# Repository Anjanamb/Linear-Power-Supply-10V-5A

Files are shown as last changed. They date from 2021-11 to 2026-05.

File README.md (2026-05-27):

# Linear Power Supply — 10 V, 5 A

> Linear bench power supply targeting **10 V / 5 A**. Concept, simulations, PCB layout, enclosure model, slides, and project report.






> ⚠ **Mains voltages involved.** Only qualified individuals should build or test this. Follow proper electrical safety practices.

---

## Topology

- Step-down transformer 230 V AC → low-voltage AC
- Linear regulation to 10 V DC at up to 5 A
- Short-circuit protection (fast electronic fuse behaviour)
- Over-voltage protection (crowbar / thyristor)
- Negative-voltage protection at output
- Foldback current limiting
- Thermal management via fan-regulation circuit
- PCB layout (Altium) + 3D enclosure (SolidWorks) + Multisim simulations

## Repository structure

```
Linear-Power-Supply-10V-5A/
├─ Circuit/
│  ├─ Fan-Regulation_Circuit.png
│  ├─ Fan-Regulation_Simulation.ms14
│  ├─ Main_Regulation_Circuit.png
│  ├─ Over-Voltage_Protection.png
│  ├─ Short-Circuit_Protection.png
│  └─ Simulation Circuit.ms14
├─ Datasheets/Over Voltage/             # Component datasheets
├─ PCB/                                 # Altium PCBs
├─ Enclosure_Design.SLDASM              # SolidWorks assembly
├─ Presentation.pptx
├─ Project Report.pdf
└─ components & datasheets.ptpm
```

## License

[MIT](LICENSE) — see [anjanamb.github.io](https://anjanamb.github.io/) for more projects.

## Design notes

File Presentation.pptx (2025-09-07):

## LINEAR POWER SUPPLY

Group No. - 05

## Basic Idea

Stepped down source
(230 V rms-15 V rms)

Short circuit protection

Regulator circuit

Current divider circuit

Feedback circuit

Foldback Current circuit

Output
(Voltage 10V
Current 5A)

Over voltage protection

## SCHEMATIC DIAGRAMS

## MAIN REGULATION CIRCUIT

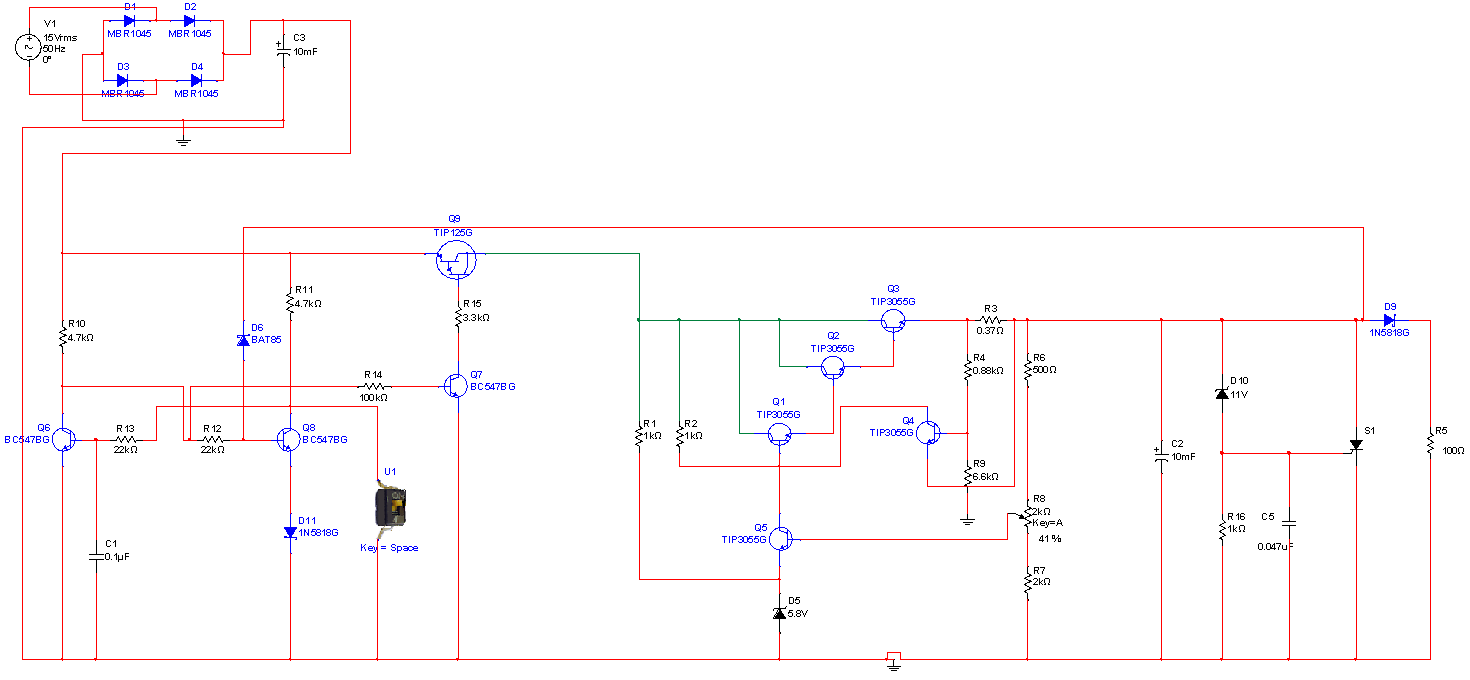
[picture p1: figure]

## FAN REGULATION CIRCUIT

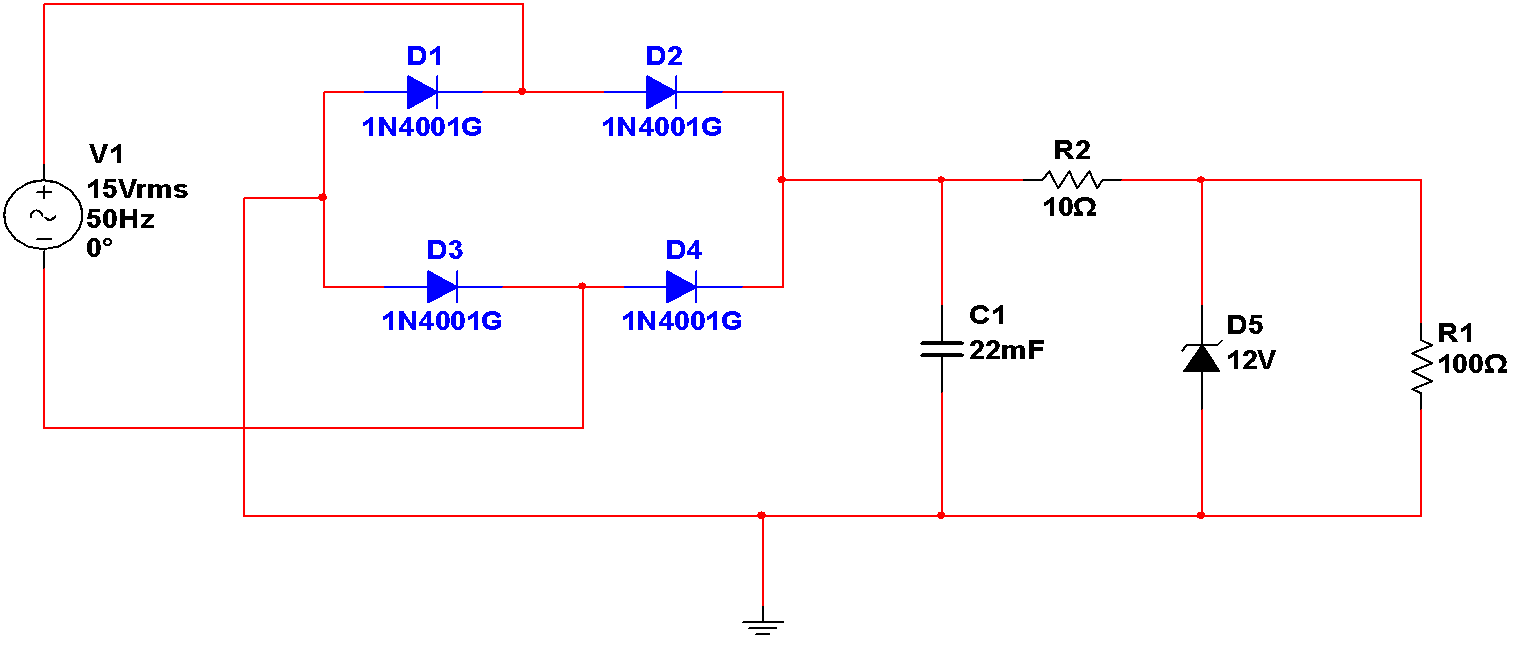
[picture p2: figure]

## CIRCUIT EXPLANATION

## Main regulation parts

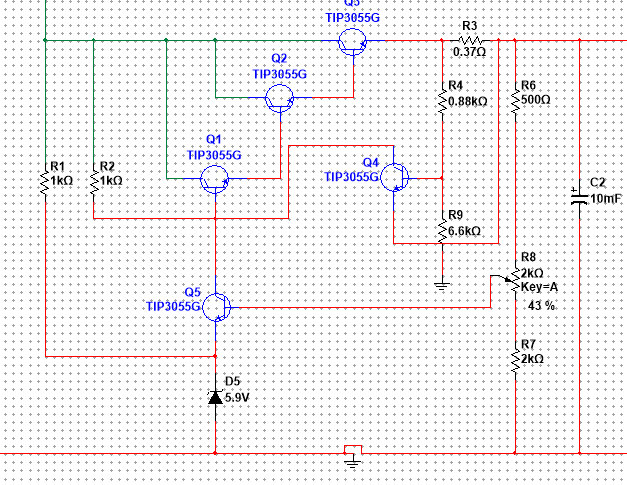
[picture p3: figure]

- Regulator
- Current divider
- Feedback
- Foldback Current

VBE(Q4)= K IL R5 + (K – 1) Vout
K= (R9 / R4+ R9)

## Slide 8

Feedback circuit Calculations
VBE(Q5) + V(D5) = R7 / (R7 + R6) * Vout
Vout = (1 + R6/R7) (VBE(Q5) + V(D5) ) 01
Vout =10v V(D5) =5.9v VBE(Q5) =0.7v
From 01, R7 ≈2 R6
Foldback current limiting circuit calculations
VB(Q4) = Vout + VBE(Q4) 01 K = R9 / R9 + R4
VB(Q4) = (Vout + R3 IL )K 02
So, Vout + VBE(Q4) = (Vout + R3 IL )K
Vout =10v ILmax=5.5A VBE(Q4) =0.7v & choose R3 =0.37Ohm
By substituting values, K = 0.889
So, R9≈8 R4.

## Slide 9

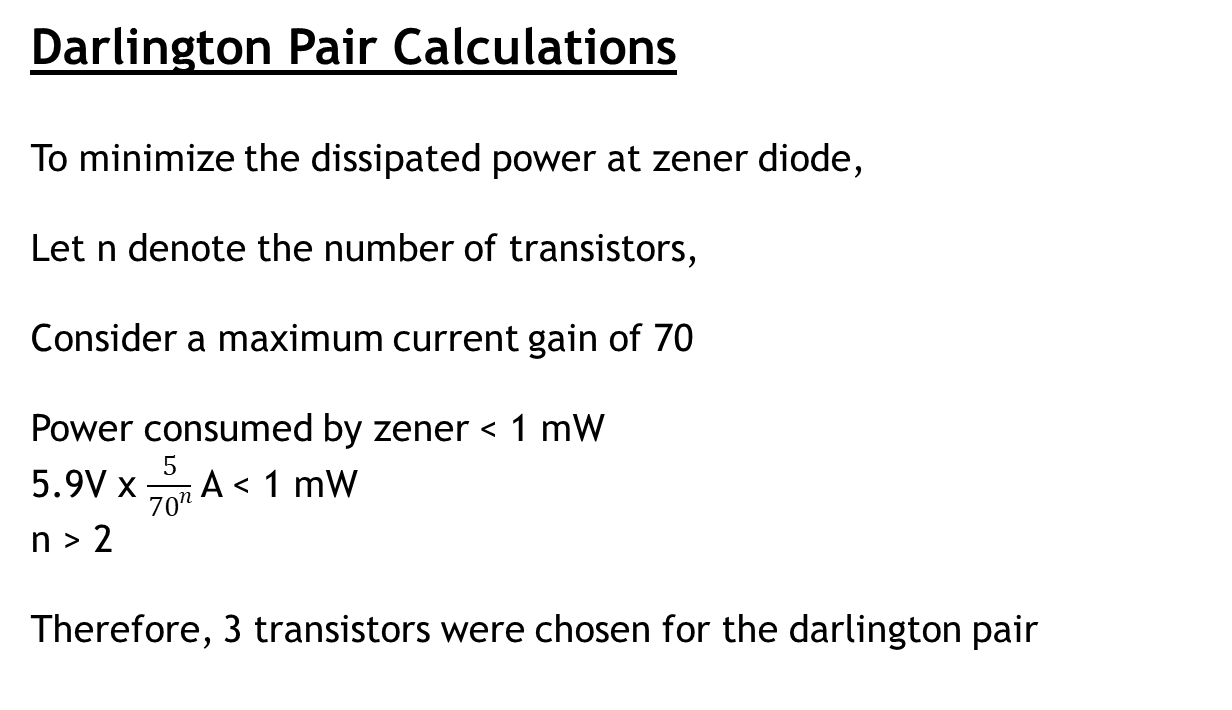
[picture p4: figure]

## Circuit Protections

- Short Circuit Protection

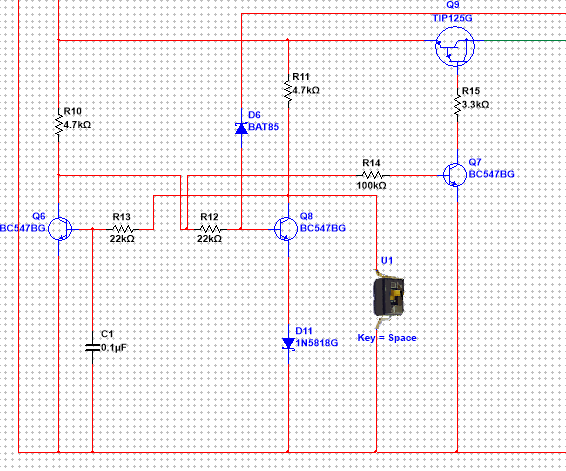
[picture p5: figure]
Screen Clipping

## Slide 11

- Over Voltage Protection
- Over Load Protection

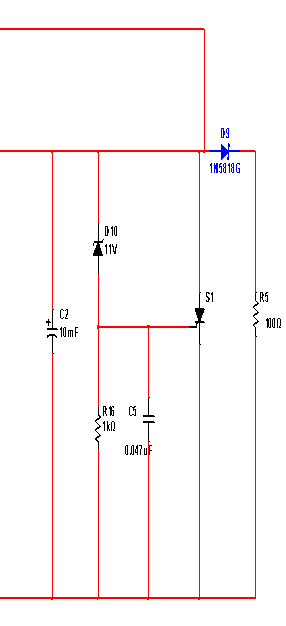
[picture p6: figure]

## Over Voltage Protection circuit calculation

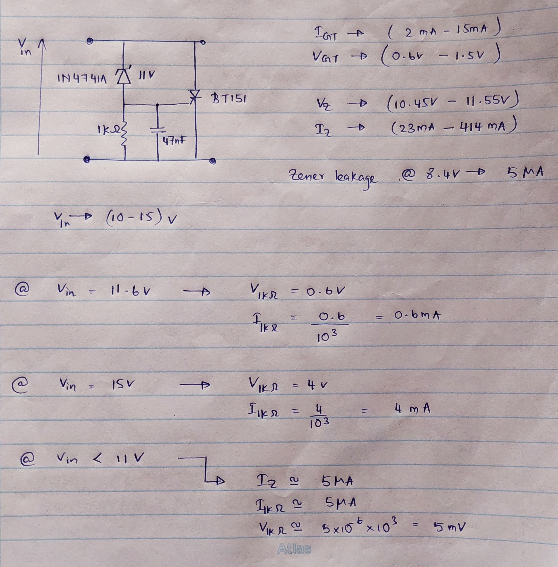
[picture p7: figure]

## SIMULATION RESULTS

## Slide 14

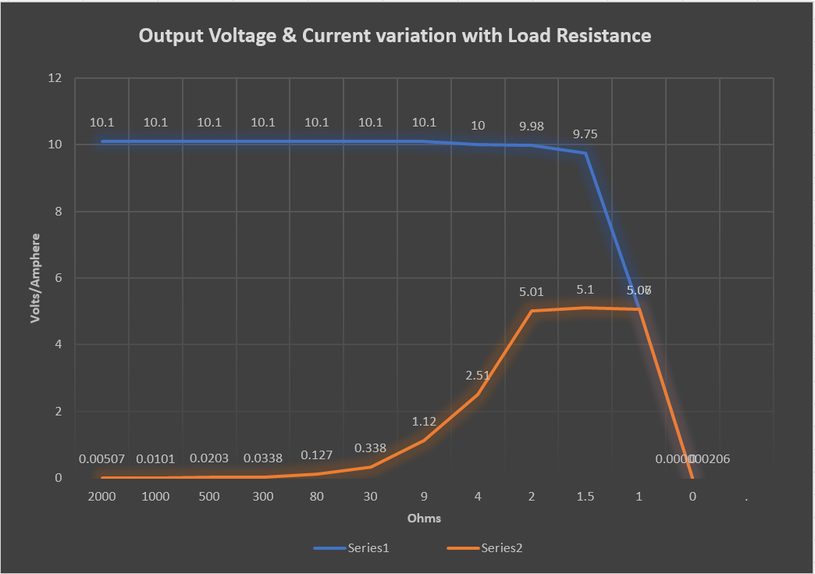
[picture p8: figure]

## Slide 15

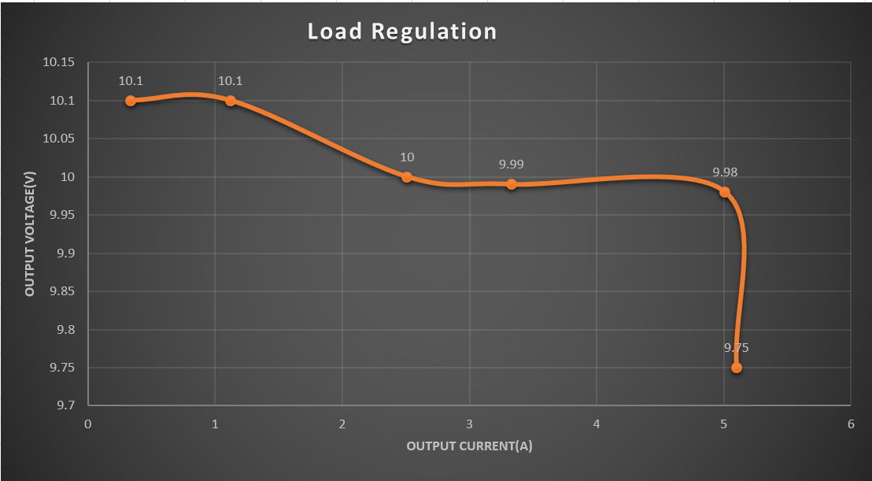
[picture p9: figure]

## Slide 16

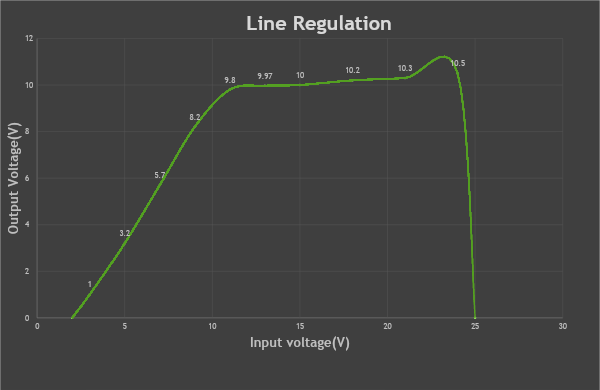
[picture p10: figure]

## Accuracy

- Accuracy = output voltage at maximum current/required output voltage
= 9.79/10 * 100%
= 97.9%

## Breadboard Implementation

Load Resistance (ohms) | Output voltage (V)
2000 | 10.2
1000 | 10.1
500 | 10.1
100 | 9.7
50 | 9
30 | 8.1
10 | 7.3
5 | 6.9
2 | 6.5

- When output current increase for small load resistance, the voltage loses from the bred board and jumper wires increases. So that output voltage dropped from a huge amount.

## COMPLETION PLAN

## ENCLOSURE DESIGN

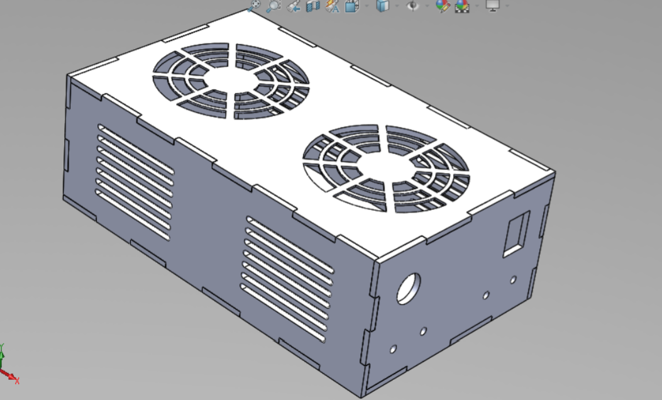
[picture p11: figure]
Screen Clipping

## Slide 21

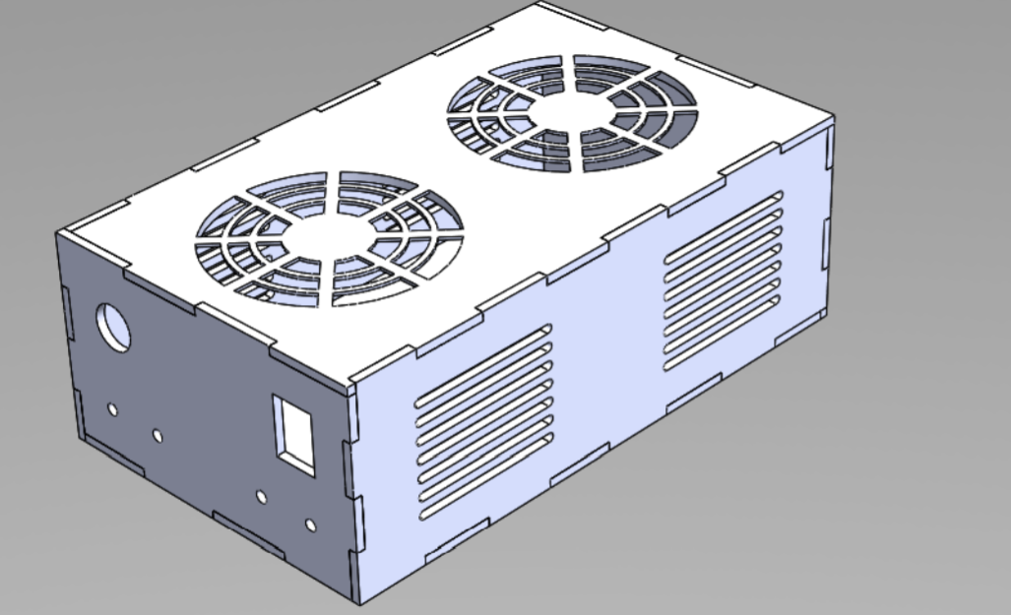
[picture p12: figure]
Screen Clipping

## PCB DESIGN

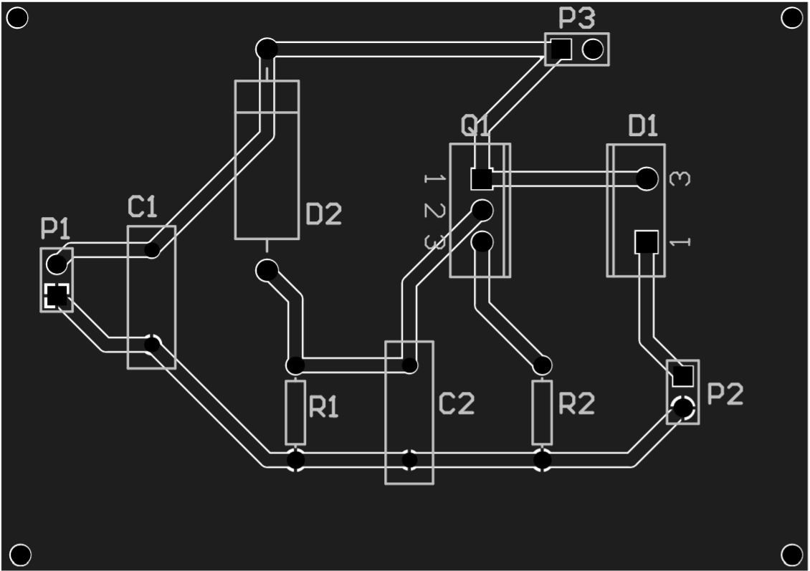
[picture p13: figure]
Screen Clipping

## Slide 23

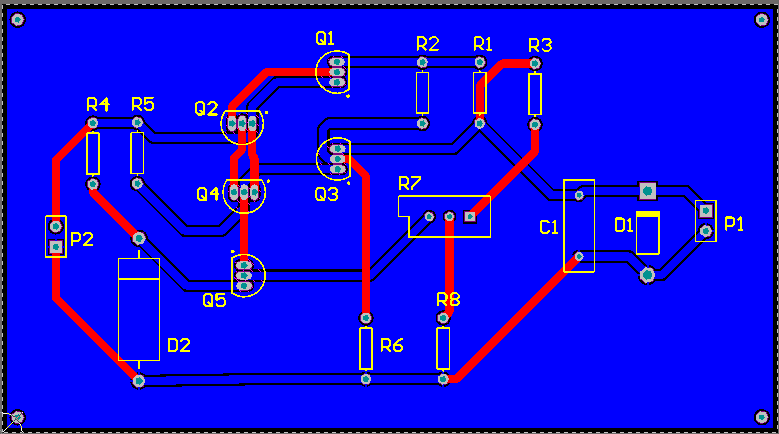
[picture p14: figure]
Screen Clipping

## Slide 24

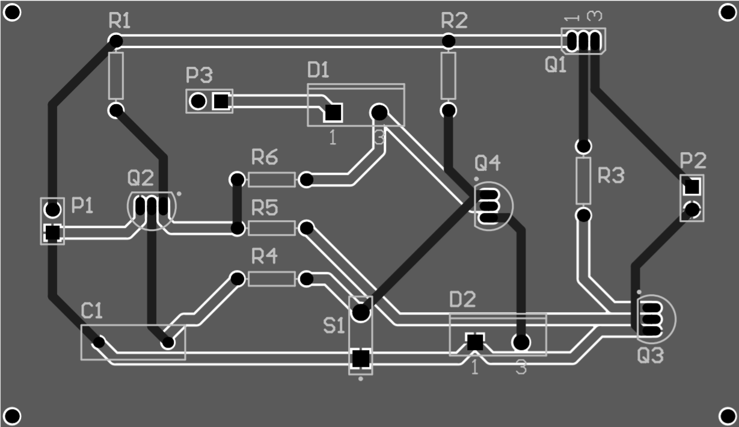
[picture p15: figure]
Screen Clipping

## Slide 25

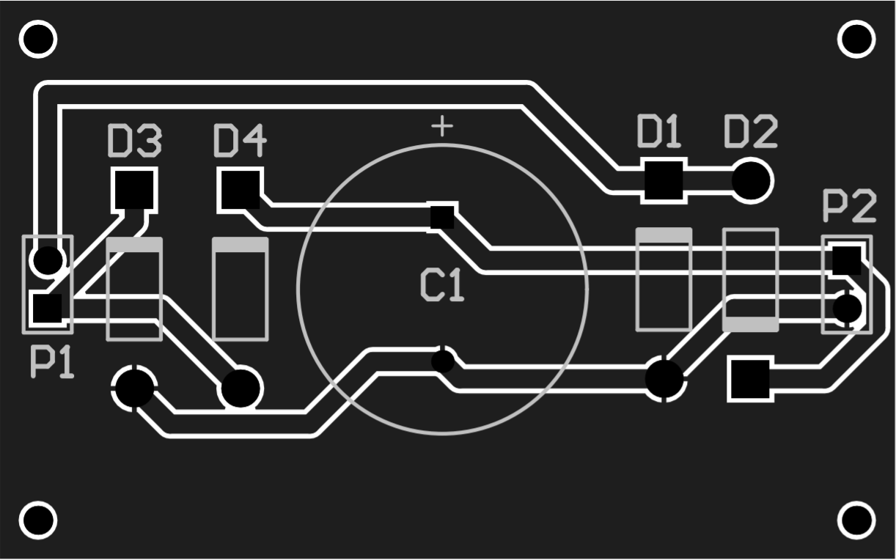
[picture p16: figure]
Screen Clipping

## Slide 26

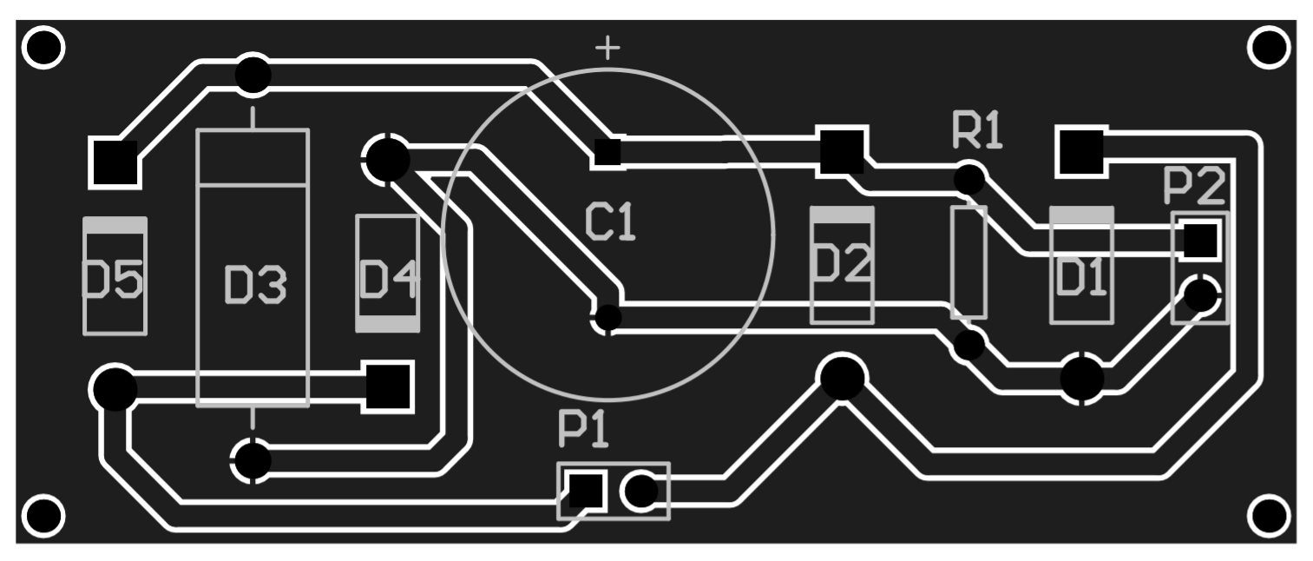
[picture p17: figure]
Screen Clipping

## THANK YOU !!

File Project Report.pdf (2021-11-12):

# Linear Power Supply

Introduction

Power supplies are used to drive a load under constant voltage/current conditions. Handling power supplies in a safer method is very crucial as the equipment attached or any human being handling it may get affected or electrocuted by excessive current or improper wiring methods. When designing power supplies several factors should be taken into consideration including efficiency, load and line regulation, short circuit protection etc. We are in need of creating a voltage regulator design from scratch to drive a high-power load (50 W) from 230 V input voltage. The circuit should give an output of 10V linear voltage with a maximum current rating of 5A.

Procedure (Proposing Method)

The main idea is quite simple. The input voltage of 230V from the main power supply should be step down using a 230V rms -15V rms transformer and the stepped down alternating current should be rectified first using diodes or bridge and then the direct current should be regulated to provide 10V. But the
problem here is that the simple voltage
regulator circuit using a zener diode as shown
in the figure, will not be appropriate to produce 5A current and drive heavy loads. Further we will have to keep the voltage
constant at 10V and limit the current at 5A
maximum.

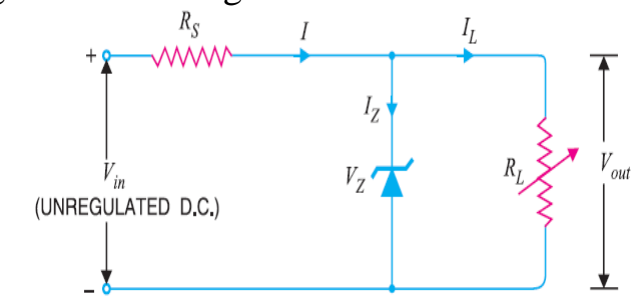
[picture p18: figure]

Therefore we thought of coming up with a circuit that includes the following peripheral circuits.

1. Regulator
2. Current divider
3. Feedback
4. Foldback Current

The regulator circuit will provide us a voltage regulation using a zenor diode of 5.9V. The regulated voltage will be further increased by a series of transistors (the base emitter voltage will be added). This takes care of the voltage regulation part. And the rest would take care of the current limiting part.

Figure 1 Normal regulator

Since current divider circuit consists of three transistors in series which is also called the Darlington Pair , we can amplify a small current of
5µA to the maximum current of 5A.

The Foldback current circuit which consists of one
transistor and a couple of resistors will ensure that the maximum current is set to 5A. This is an alternative for the current limiting circuit, which performs as the same but limits the short circuit current further and the base voltage of the transistor will be set to a higher value through the voltage divider circuit which consequently
reduces the power dissipation at the short circuit
condition.


The feed back circuit consisting another transistor will ensure that any excessive current is handled properly and it is routed to the right place.(surge limiting transistor) This also provides Overload protection to the circuit.

Further to ensure the the heat dissipated in the circuit is cooled down a small fan will be used. And another simple regulating circuit using zenor diode would be enough to drive this fan.

Circuit Protections

1. Short circuit protection
A bistable multivibrator circuit is used here to provide the short circuit protection. The circuit will quickly recognize the short circuit condition and quickly change its state so that there won’t be power supplied to the main regulator circuit part and the output current will be 0. Through switch this circuit is needed to be reset to its original stage, as soon as the short circuiting problem is identified and corrected. In short, this performs as the electronic fuse.

Figure 2 Main regulator circuit

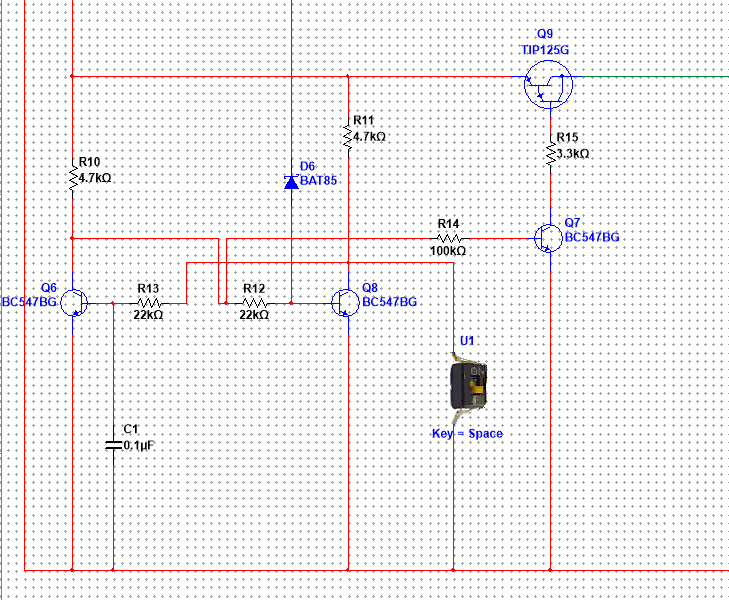
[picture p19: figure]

Figure 3 Short Circuit Protection

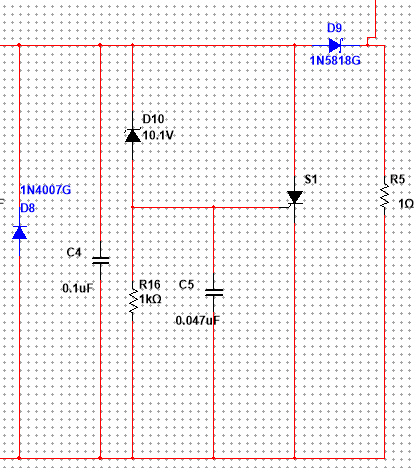
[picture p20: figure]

2. Over Voltage Protection
The crowbar circuit shown in the figure is used to provide overvoltage protection to the main regulator circuit. Whenever the threshold voltage of 11V is reached at the the crowbar circuit, thyristor gets activated and it will shortcuit the circuit through the thyristor, thereby moving the circuit into short circuit condition and the bistble multivibrator circuit will change state.
3. Negative voltage Protection
A simple diode as shown in figure 4 across the output will change the direction of the current in the circuit when the
input voltage suddenly turns out to be negative.
4. Overload Protection
The feed back pheripheral circuit mentioned above will provide the Overload protection to the circuit.

Preliminary Design ( Block Diagram)

### 1. Main regulator Circuit

Figure 4 Overvoltage protection and negative voltage protection

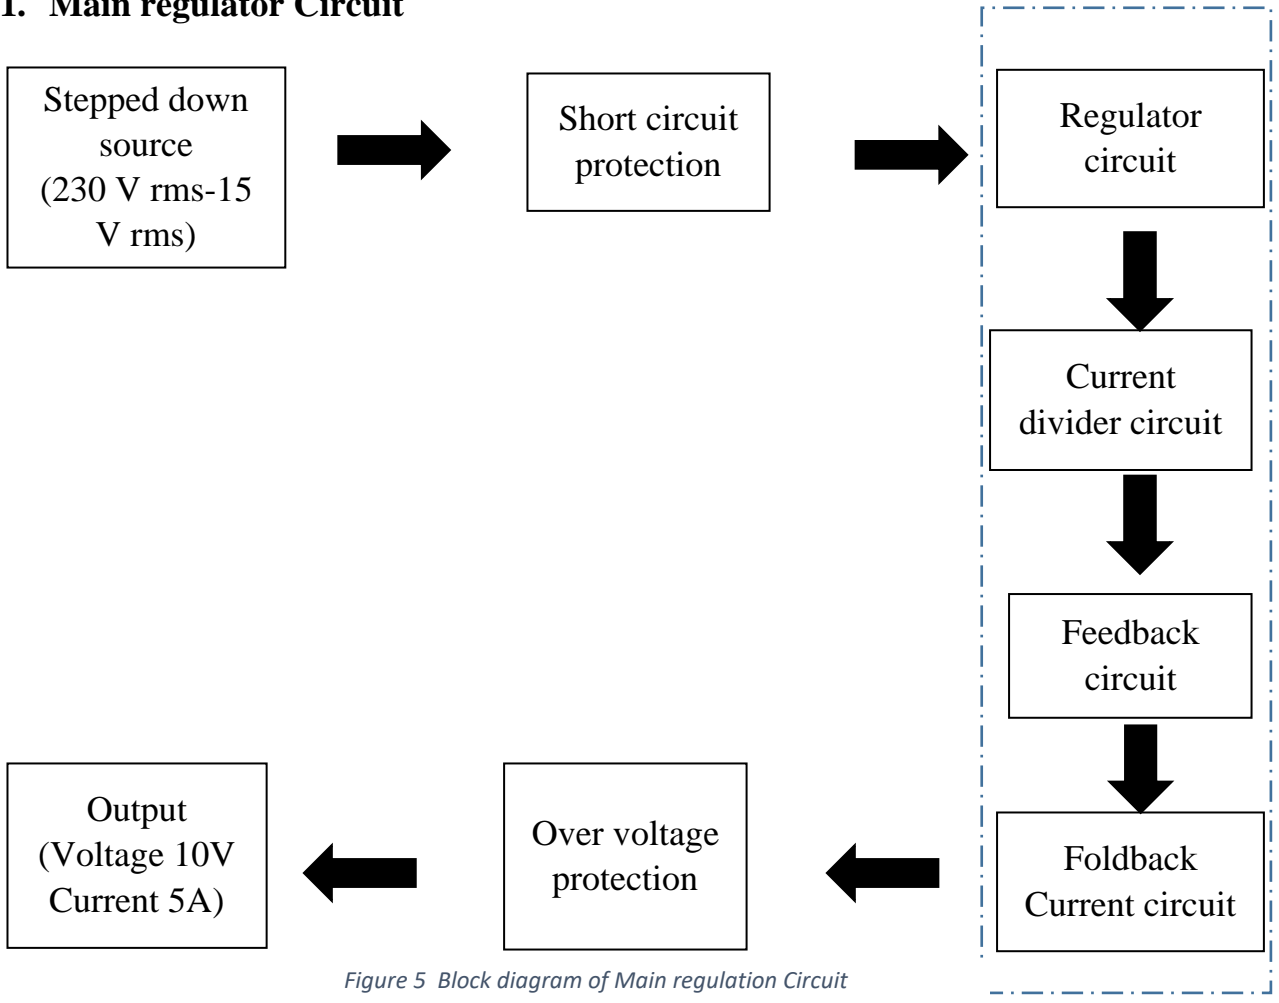
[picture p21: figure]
Stepped down source (230 V rms-15 V rms); Current divider circuit; Regulator circuit; Feedback circuit; Foldback Current circuit; Output (Voltage 10V Current 5A); Over voltage protection; Short circuit protection

Figure 5 Block diagram of Main regulation Circuit

### 2. Fan Regulating Circuit

Component selection and discussion

1. 230 V rms – 15V rms transformer – to step down the input voltage
2. Tip3055G – Has a current gain of 70, output current can go upto 15A annd 60V, has an excellent safe operating area considering power disspation, heat and other factors. So this could be used in peripheral circuits such as Current limiting, current divider and feedback.
3. MBR1045 Diodes – has the capability to withstand 10A and 90V, less power dissipation and it is readily available at shops.
4. BC547BG, TIP125G – To facilitate the bistable multivibrator circuit
5. Potentiometer – to control the feedback circuit
6. Zener diode – 5.8V for main regulator circuit and 12 V for Fan regulation circuit
7. 1N5818G, BAT85 – This is a Schotkky Diode which would perform the function as diode but have minimal voltage drop across it.
8. Fan (12V, 0.14A) – to control the heat dissipated in the main circuit
9. Other miscellaneous components such as resistors and capacitors. Values are mentioned in the conceptual design provided below.

Conceptual design

Fan Regulation Circuit

Input Source
(230 V rms)

Regulator
circuit | Fan

Figure 6 Block Diagram for Fan Regulation

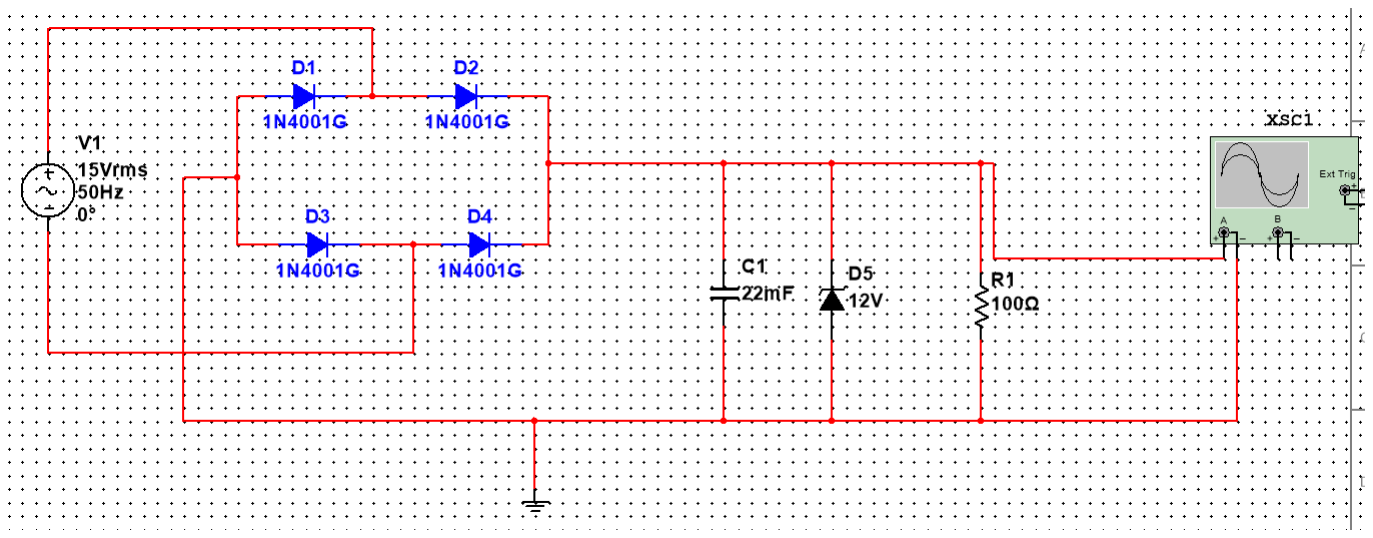
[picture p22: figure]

Figure 7 Fan Regulation Circuit

Main Regulation Circuit

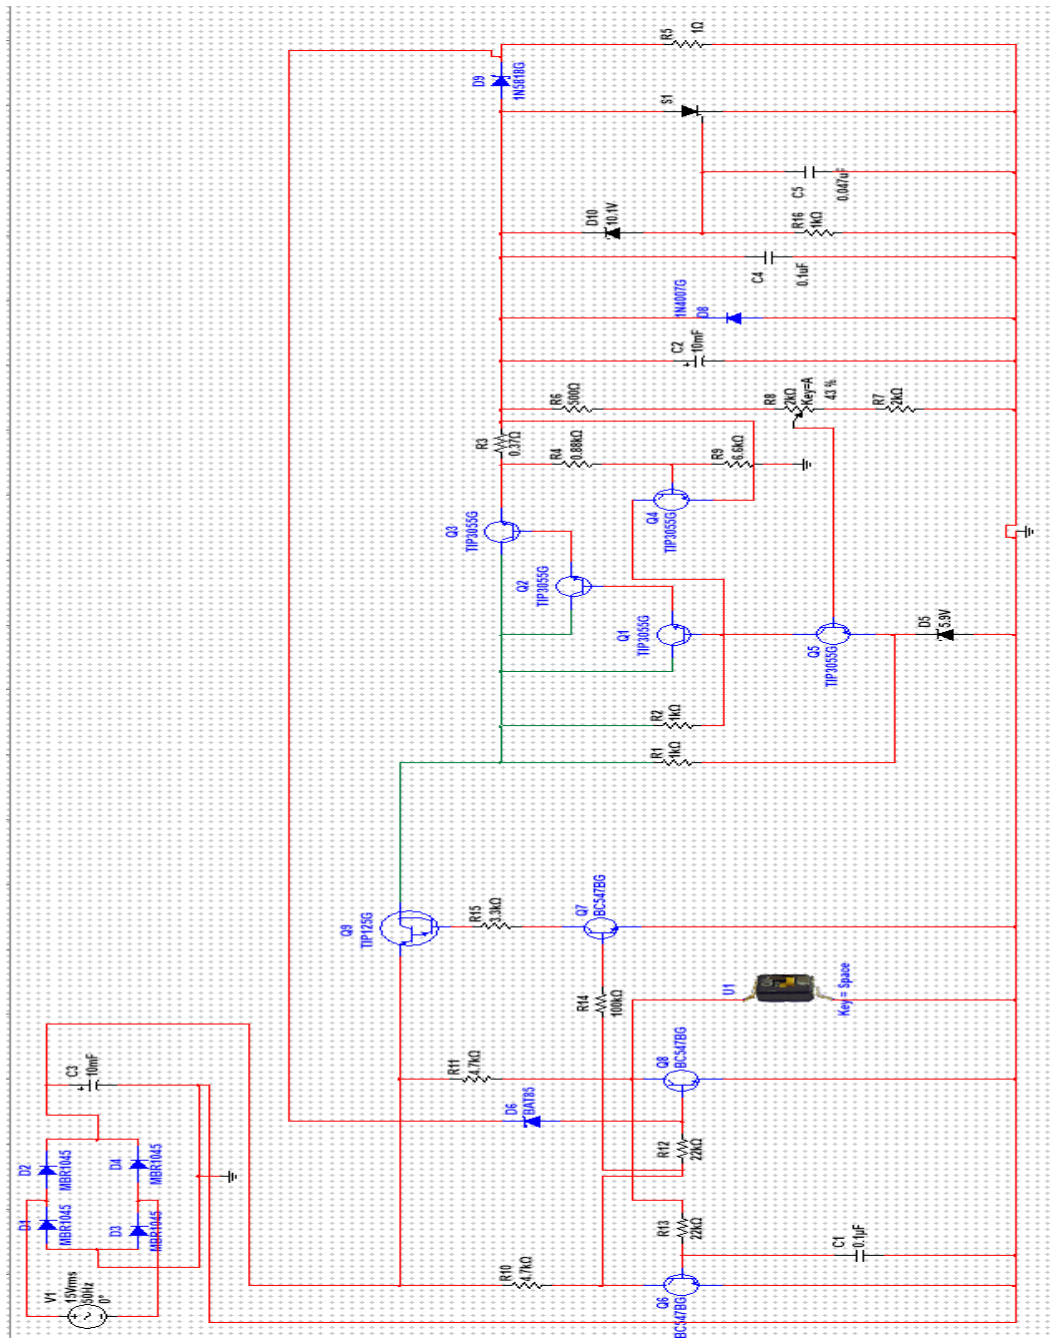
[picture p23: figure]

Figure 8 Main Regulation Circuit

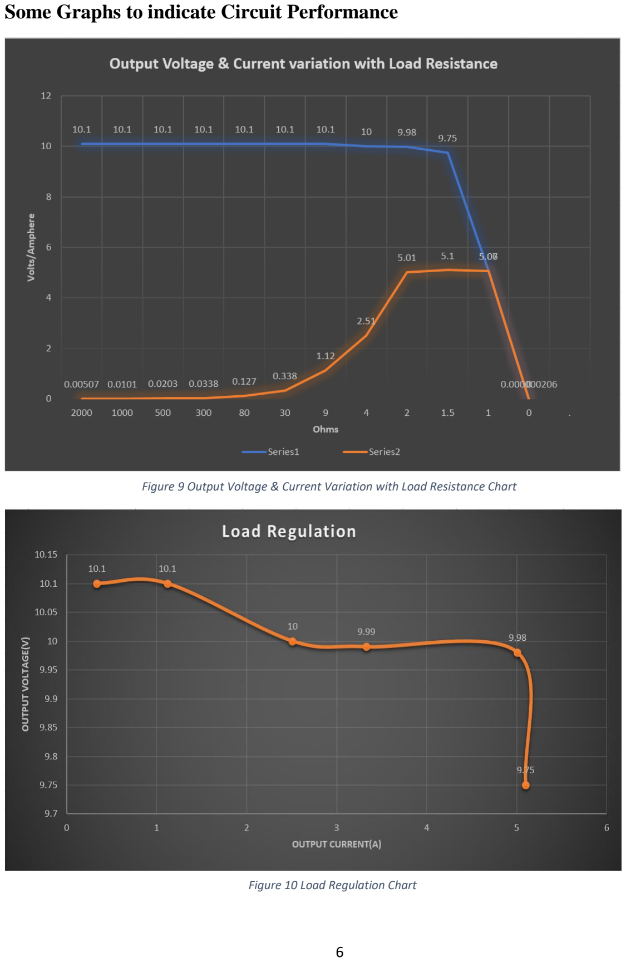
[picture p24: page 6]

Some Graphs to indicate Circuit Performance

Figure 9 Output Voltage & Current Variation with Load Resistance Chart

Figure 10 Load Regulation Chart

Work Load Allocation

Group No. 5

Name | Index No. | Work allocated
Nirhoshan S. | 180428T | Designing the Main regulation Circuit
Nayanajith T.M.S | 180417J | Designing the Fan regulation Circuit and enclosure , drawing the charts
Bandara H.M.A.M. | 180060G | Designing the Over voltage protection
Jayapala P.S.C | 180265N | Designing the short circuit protection

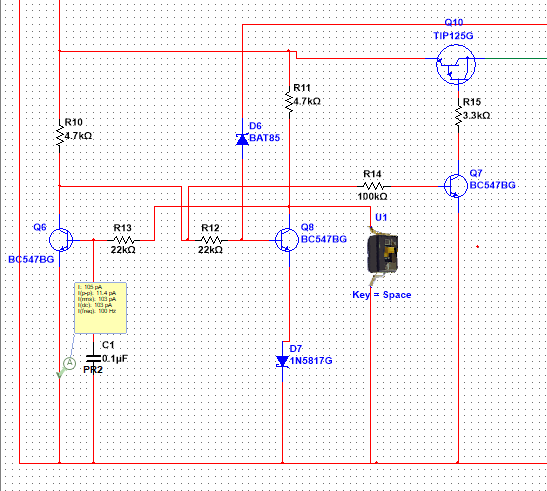
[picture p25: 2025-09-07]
Circuit/Short-Circuit_Protection.png

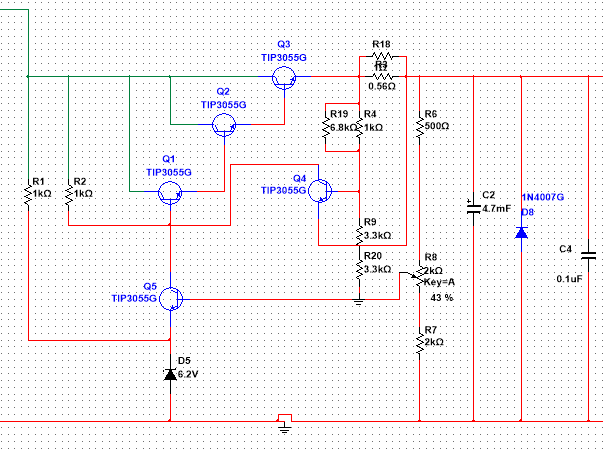
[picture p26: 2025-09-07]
Circuit/Main_Regulation_Circuit.png

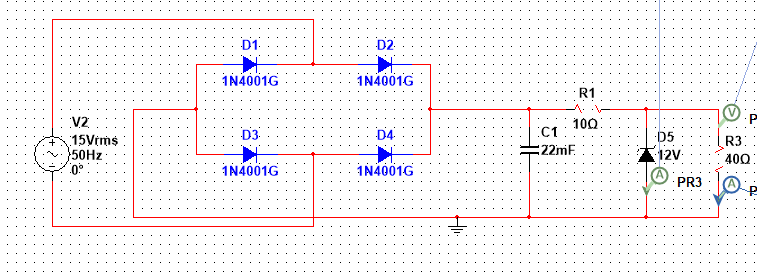
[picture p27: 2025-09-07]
Circuit/Fan-Regulation_Circuit.png

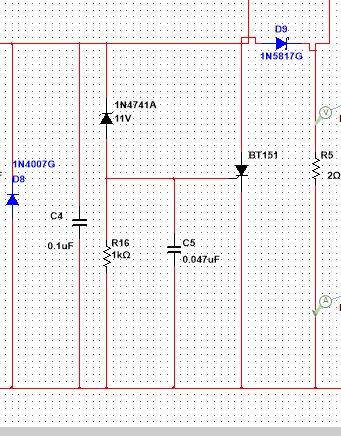
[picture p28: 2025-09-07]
Circuit/Over-Voltage_Protection.png

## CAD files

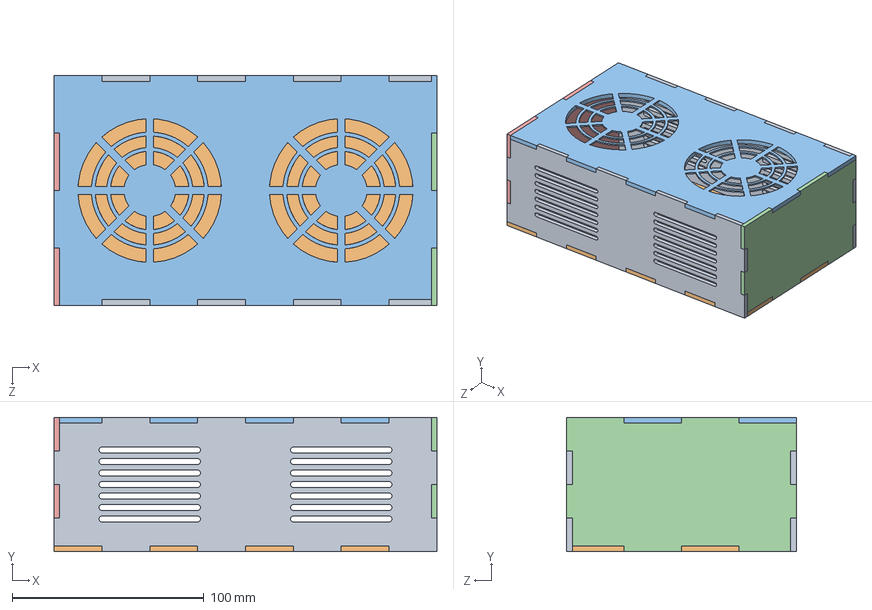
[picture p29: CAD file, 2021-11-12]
Enclosure_Design.SLDASM
200.0 x 70.0 x 120.0 mm
R side x 2
Part1^Assem1
Part2^Assem1
Part3^Assem1
Part4^Assem1
